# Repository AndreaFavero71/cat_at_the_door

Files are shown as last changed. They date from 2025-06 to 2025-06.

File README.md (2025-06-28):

# CAT AT THE DOOR – A system to detect and notify when your cats are waiting at the door.
<br><br>
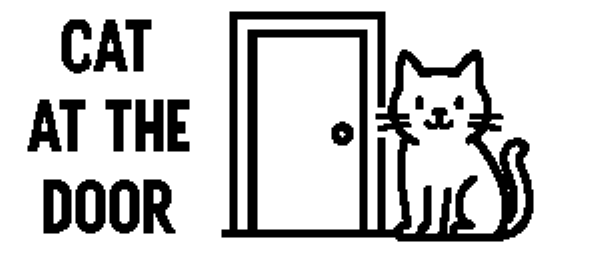
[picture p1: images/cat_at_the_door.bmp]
title image


<br><br>
## Project overview

**CAT AT THE DOOR** is a wireless system that detects when your cat is waiting at the door and notifies you via a portable device.  

It’s ideal if:  
- You cannot install a cat flap or automatic pet door.
- You like to let your cats roam outside.
- You want to be notified the moment your cat is ready to come back in.

This project uses two devices communicating via **LoRa**:
- A **stationary unit** with radar + BLE detection, placed inside near the door.
- A **portable unit** with e-paper display + buzzer, that you carry with you.

<br><br>
## Project motivation
I was perfectly happy building machines no one asked for, until my wife kindly reminded me that we also have cats… not just robots.  
Once I accepted the challenge, the project became increasingly interesting, giving me the opportunity to explore technologies I had never used before.

<br><br>
## Demo video

MACCHIA, one of our cats, comes back home after wandering in the garden for over an hour:

Watch the Demo (https://youtu.be/0kiuHv76AjQ)

<br><br>
## Key features

- Detects when one or more cats approach your door
- Uses BLE tags for individual cat recognition (supports 1–4 cats)
- Radar motion sensing, customizable via Bluetooth app
- Visual notification via e-paper display
- Audible alert via buzzer (optional)
- Portable device is battery-powered with sleep mode
- Communication via LoRa, a **Lo**ng **Ra**nge low-power wireless communication system (reliable even through walls/floors)
- Optional Wi-Fi sync for correct date/time
- Rotary encoder menu interface
- 3D printed cases included (STL & STEP)

<br><br>
## Required hardware (summary)

| Qty | Component | Notes |
|-----|---|---|
| 2 | Heltec Wi-Fi LoRa 32 V3 | With antenna + JST battery connector |
| 1+  | Tile Sticker BLE tag (per cat) | Use the Tile app to activate |
| 1 | HLK TD2010C radar module | Tuned via HLKRadarTool app |
| 1 | 2.9" Waveshare e-paper display | Black & white |
| 1 | 3.7V 2200mAh LiPo battery | For portable device |
| 1 | Rotary encoder + push-button | For settings menu |
| 1 | Buzzer (3.3–5V, with transistor) | For optional alerts |
| | USB-C panel mount sockets | Power and recharging |
| | 3D printed case set | STL and STEP files provided |
| | Aluminum tape | Blocks radar from sensing inside room |
> Please read the manual for full instructions before proceeding.

<br><br>
## Quick start
1. Attach a **Tile Sticker BLE tag** to your cat’s collar and retrieve its MAC address (e.g., using *nRF Connect* app)
2. Flash **MicroPython** onto both Heltec Wi-Fi LoRa 32 V3 boards
3. Upload files via **Thonny** to both boards (portable and stationary)
4. Edit `ble_tags.json` and `config.json` with your own settings
5. Tune radar sensitivity and detection area using the **HLKRadarTool** app
6. Power up both devices and observe how it detects when your cat returns!

> This is not a plug-and-play kit. Expect some assembly, soldering, BLE scanning, and radar tuning.  
> Please read the manual for full instructions before proceeding.

<br><br>
## LoRa Power Negotiation System

This project features a **dynamic LoRa power adjustment** mechanism that minimizes transmission power while maintaining reliability.  
Here's how it works:

1. Both devices begin with the default `tx_power` value set in `config.json`.
2. After each successful data exchange, they evaluate the received signal strength (RSSI):
   - If **RSSI is too low**, the device adds a `<` character to its reply to request **more power**.
   - If **RSSI is too high**, the device adds a `>` to request **less power**.
   - If RSSI is within the configured window, no change is requested.
3. If no reply is received for 4 consecutive transmissions:
   - The sending device increases its transmission power to **22 dBm** temporarily.
4. If no reply is received after 15 failures:
   - It resets the transmission power to the default value, assuming the peer is off.

> This simple yet effective mechanism helps conserve battery life without compromising reliabile communication.

<br><br>
## LoRa Duty-Cycle Compliance

LoRa frequencies and transmission limits are **regulated** in most countries.  
For example, in the EU (including the Netherlands), the max **duty cycle is 1%** (36 sec/hour).

This system:
- Calculates Time-on-Air (ToA) based on your number of cats and LoRa settings
- Automatically increases the transmission interval if the estimated duty cycle exceeds the limit
- Provides console feedback via Thonny when tuning or debugging

> All related parameters (LoRa power, frequency, spreading factor, etc.) are adjustable in `config.json`.

<br><br>
## Detailed manual

All build instructions, tuning tips, and troubleshooting steps are in the downloadable 70+ page guide:  
📄 [How_to_make_CAT_AT_THE_DOOR.pdf](doc/How_to_make_CAT_AT_THE_DOOR.pdf)

| #  | Section | Description |
|----|---|---|
| 1  | Introduction | Project goals and context |
| 2  | Supplies | Full list of parts |
| 3  | Make | 3D printing, wiring, assembling |
| 4  | Program | Flashing and uploading code |
| 5  | Tuning | Radar and BLE tuning |
| 6  | Troubleshooting  | Common issues and fixes |
| 7  | How to use it | Practical operation |
| 8  | Info | Legal, safety, and technical remarks |

<br><br>
## ⚠️ System Limitations

While the system works reliably with proper setup, it’s important to be aware of its current limitations:

- **Radar sensitivity to movements (its own job :smile:)**  
  If the radar moves, it detects movement; The stationary device should not move.  
  The mmWave radar may detect raindrops as movements.

- **Radar tuning is essential**  
  Each installation requires some trial and error. Radar positioning and threshold tuning are necessary and can take time.

- **BLE Tag compatibility**  
  Only BLE tags with fixed MAC addresses can be used. **Apple AirTags** are not compatible due to MAC address randomization.

- **Size of BLE tag**  
  The Tile Sticker is compact but may still feel bulky on very small cats.

- **Not suitable for automatic door control**  
  This project only **notifies** when your cat is outside, it does **not open** any doors or actuators.

- **Radar field of view**  
  The mmWave radar has an approximate horizontal detection angle of **60 degrees**. This is sufficient to cover a door-sized area.  
  However, if your cat tends to return from wider angles or corners not covered by this range, you may need to reposition the radar.  
  Adding a second radar module shouldn't take too much effort, and it would surely wider the coverage.

- **Intermediate DIY skills**  
  Basic soldering, 3D printing, and firmware flashing are required. Beginners can follow the guide, but the effort is non-trivial.

> Despite these limitations, with a bit of care during setup, the system proves to be a helpful, fun, and very practical solution.

<br><br>
## Where to begin

If you're interested:

1. Skim the manual once to get a general idea.
2. Let it sit for a day—yes, really!
3. Read it again more carefully.
4. You'll then know exactly what to do next.

<br><br>
_Made by Andrea Favero – for our cats Freya and Macchia_

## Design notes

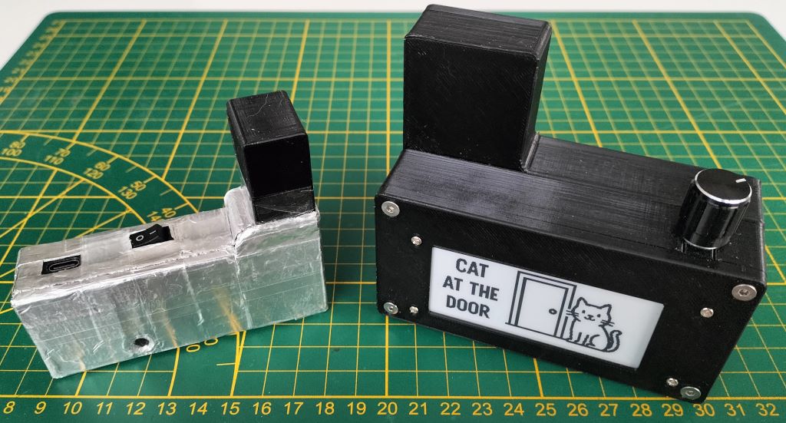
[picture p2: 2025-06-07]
images/devices.jpg

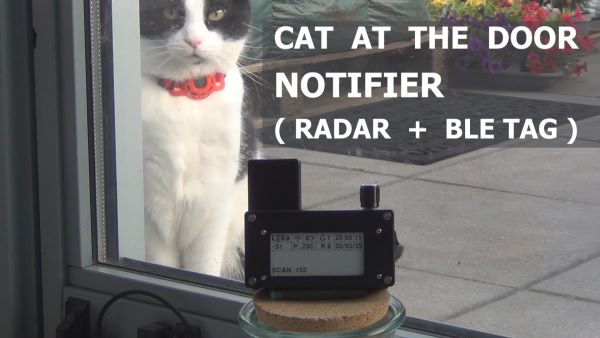
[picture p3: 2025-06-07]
images/title.jpg

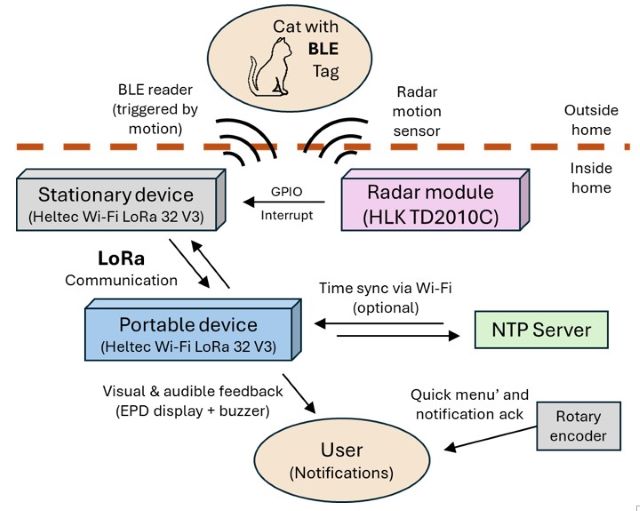
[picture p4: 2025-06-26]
images/System_achitecture.jpg

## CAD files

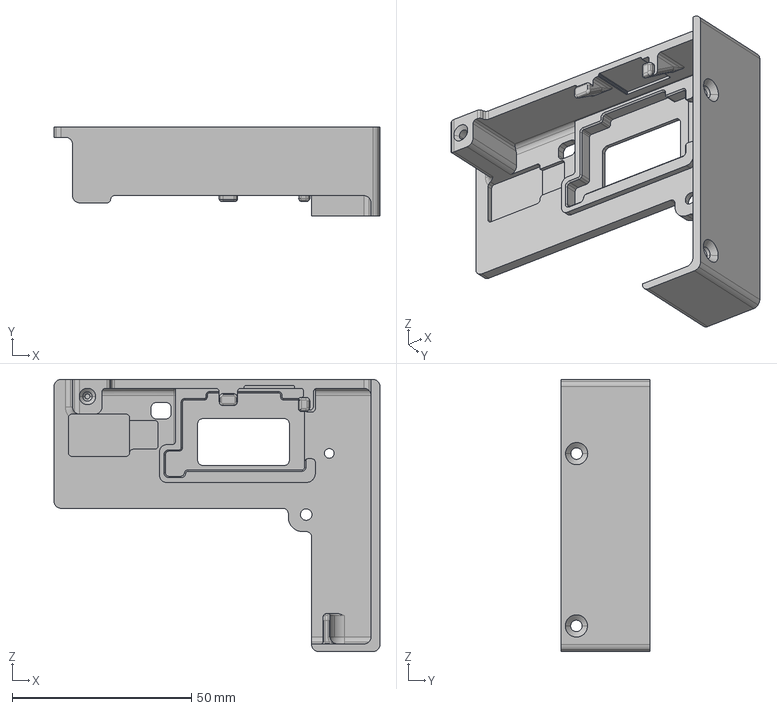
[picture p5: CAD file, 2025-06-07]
stp/Cover_stationary.stp
91.0 x 24.9 x 76.0 mm

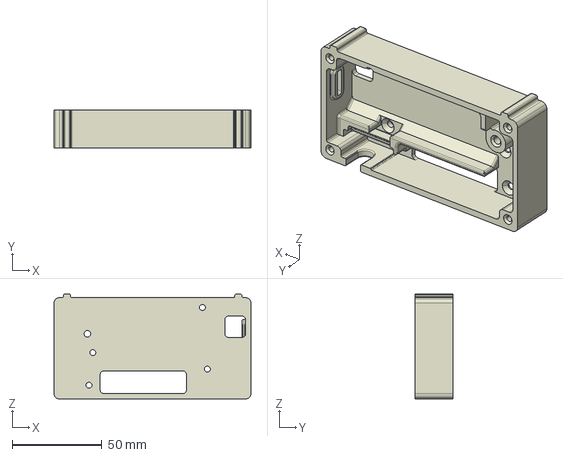
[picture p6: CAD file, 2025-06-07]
stp/Case_EPD_portable.stp
109.6 x 20.9 x 58.4 mm

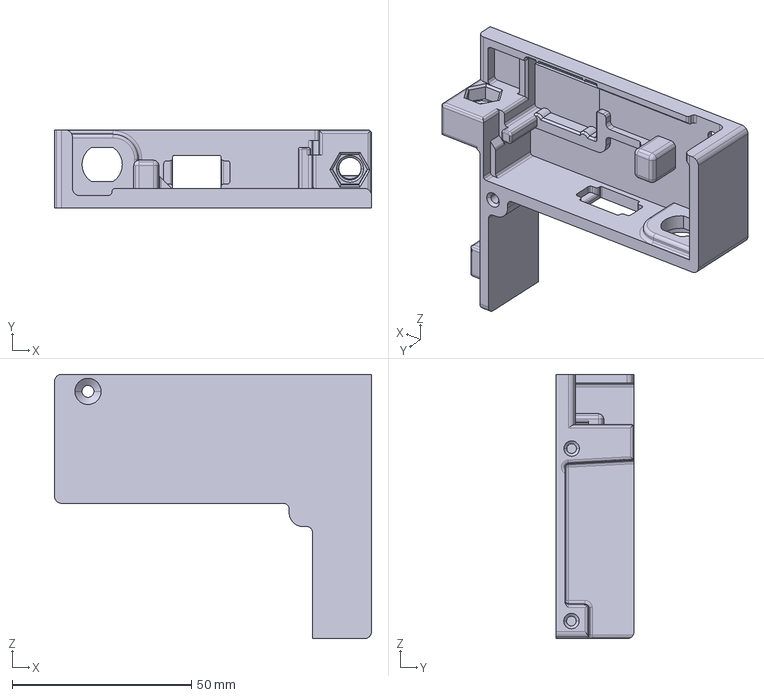
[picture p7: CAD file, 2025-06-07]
stp/Case_stationary.stp
88.4 x 21.8 x 73.8 mm

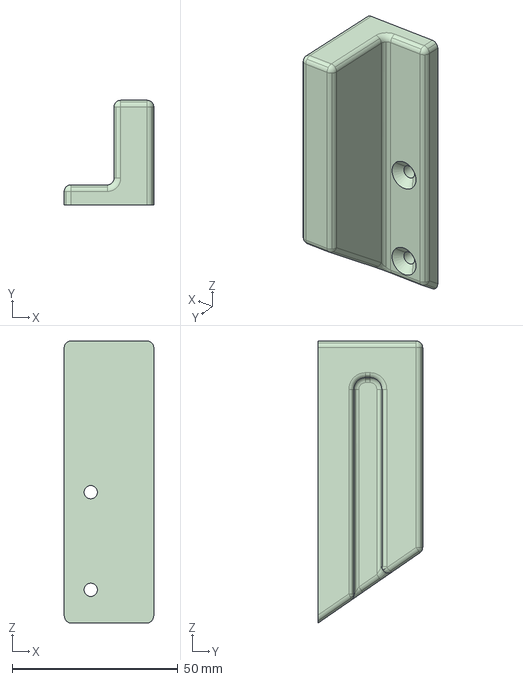
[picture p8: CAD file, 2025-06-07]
stp/Support_L.stp
27.0 x 31.5 x 85.0 mm

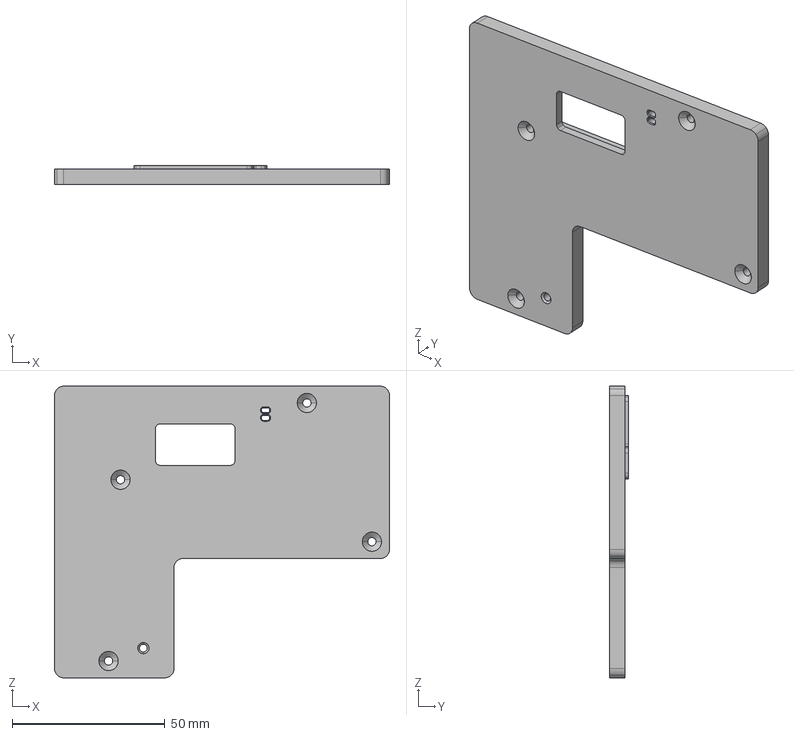
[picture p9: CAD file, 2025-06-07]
stp/Cover_Board_portable.stp
109.6 x 6.22 x 95.4 mm

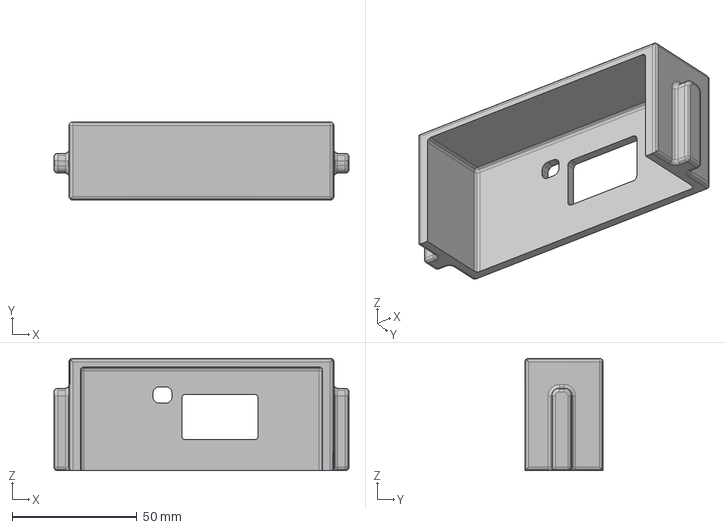
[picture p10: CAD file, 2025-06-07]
stp/Over_cover.stp
118.0 x 31.3 x 45.0 mm

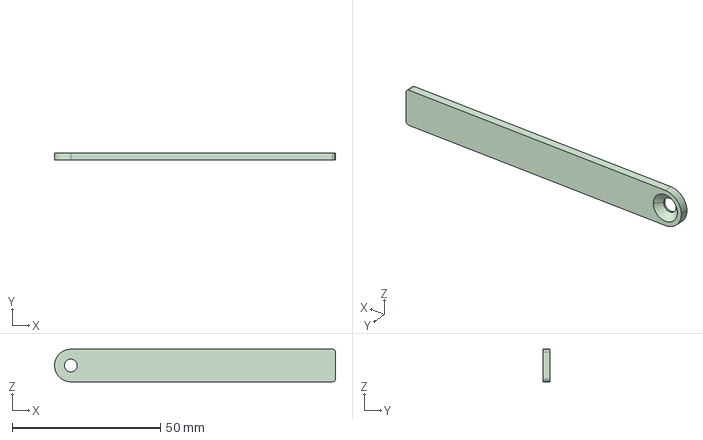
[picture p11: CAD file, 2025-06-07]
stp/Battery_holder.stp
94.7 x 2.50 x 11.0 mm

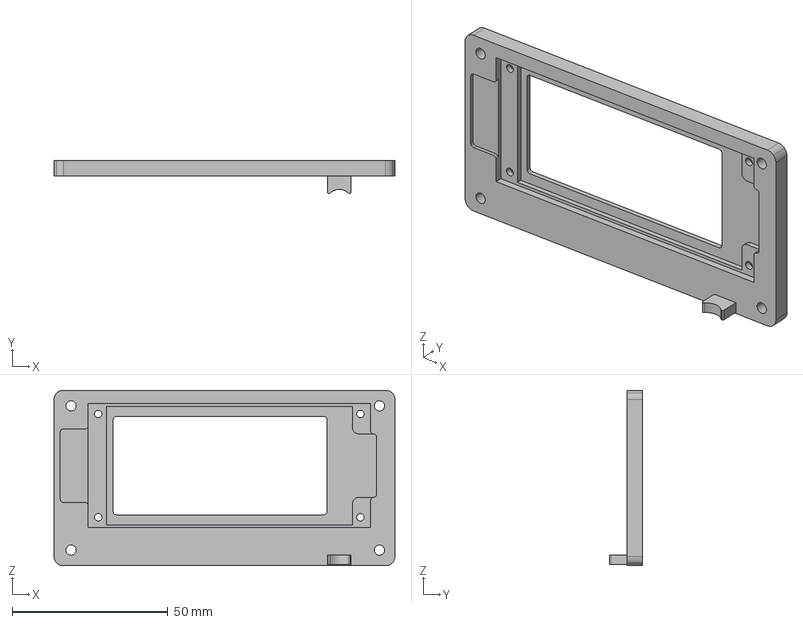
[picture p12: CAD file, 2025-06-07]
stp/Cover_EPD_portable.stp
109.6 x 10.8 x 56.4 mm

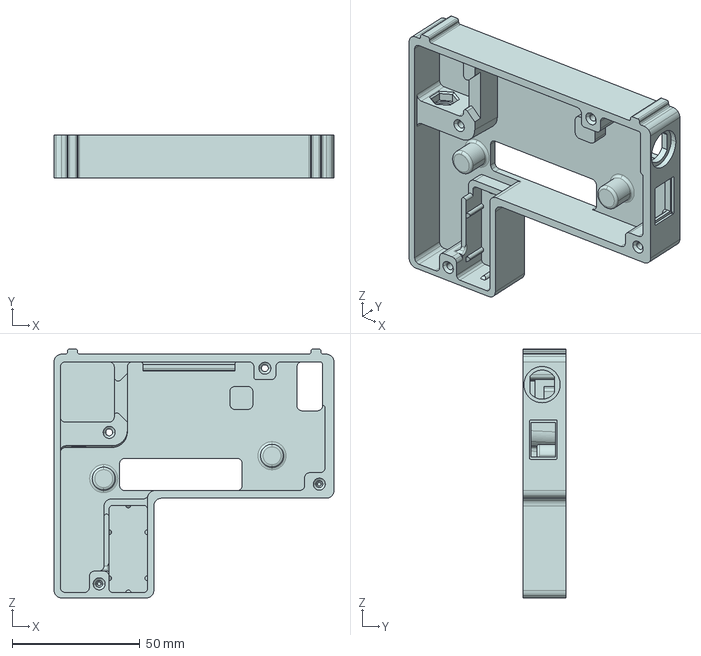
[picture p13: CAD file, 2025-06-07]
stp/Case_Board_portable.stp
109.6 x 17.0 x 97.4 mm

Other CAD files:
stp/Support_R.stp
stl/Battery_holder.stl
stl/Case_Board_portable.stl
stl/Case_EPD_portable.stl
stl/Case_stationary.stl
stl/Cover_Board_portable.stl
stl/Cover_EPD_portable.stl
stl/Cover_stationary.stl
stl/Over_cover.stl
stl/Support_L.stl
stl/Support_R.stl

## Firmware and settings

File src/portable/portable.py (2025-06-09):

"""
Andrea Favero, 20250608

'Door at the door' project
Code for the portable device
Rev 0.2


Hardware:
- Heltec WiFi LoRa 32 V3 board (based on ESP32-S3)
- e-ink 2in9V2 display (B&W) from Waveshare
- LiPo battery
- Encoder
- buzzer


High level Logic:
- Portable device periodically inquires the stationary device, via LoRa.
- The stationary device replies with info whether 'cats at the door' are detected.
- If cats are detected, the buzzer is activated and info are plot to the screen.
- Via the encoder push-button the buzzer can be stopped.
- 'cats at the door' reminder comes back to screen.
- 'cats at the door' reminder can be ackowledged by a long push-button pressing.


Energy:
- Portable device uses about 80 mWh, when LoRa updates every 20s.
- In between LoRa connections:
   - LoRa chip (SX1262) goes in sleep mode (settings retention).
   - MCU goes in lightsleep, if radar doesn't detect something.
- MCU goes deepsleep if timeout is reached (device forgotten 'ON').
- Inform the other device to adjust the LoRa signal power when too low or too high.


EPD Display:
- LoRa icon, if latest coomunication was established, and signal strenght.
- WiFi icon, if latest WiFI connection was established.
- Battery icon, with charge level periodically checked on the battery voltage.
- Bel icon if enabled, and related number of buzzer repeats
- Date and time.
- Cat icon when the stationary's device radar has sensed something.
- Cat's name and BLE tag RSSI level, when radar senses and BLE in range.
- Timeout icon right before deepsleep, if timeout is reached.


Config:
- Most of the settings in config.json file.
- Cats'names and related ble mac addresses in ble_tags.json
"""




###########################################################################################
# prints to the Shell to show the code is running #########################################
###########################################################################################

print(f"\n{'#' * 60}")
print(f"{'#' * 12}    Portable device started ...    {'#' * 13}")
print(f"{'#' * 60}\n")



###########################################################################################
# EPD library import and fast feedback on display #########################################
###########################################################################################

from epd2in9_V2 import EPD, Display                 # import edp driver

with open("lib/welcome_icon.bin", "rb") as f:       # opens the binary file with welcome bmp image
    welcome_icon = bytearray(f.read())              # makes a bytearray from the image

epd = EPD(width=128, height=296, orientation=90)    # valid orientations are 0, 90 and 180
epd.init_Fast()           # wake the epd up from sleep
epd.buffer = welcome_icon # fills the framebuffer with the welcome_icon
epd.get_buffer()          # rotates buffer and send it to EPD (portrait write to EPD, taking ca 60ms)
epd.display()             # plots the buffer to the display (takes ca 1.8 secs)
epd.sleep()               # prevents display damages on the long run (command takes ca 100ms)

welcome_icon = None       # release welcome_icon to free up some memory 



###########################################################################################
# Libraries import ########################################################################
###########################################################################################

from machine import Pin, ADC, PWM, RTC, Timer, deepsleep, lightsleep, WDT, SoftI2C
from machine import reset_cause, PWRON_RESET, HARD_RESET, WDT_RESET, DEEPSLEEP_RESET, SOFT_RESET

import sys, network, ntptime, json, ubluetooth, gc, ssd1306, utime, struct

from datetime_converter import DateTimeConverter    # date time conversion w/wo internet
from rotary_irq_esp import RotaryIRQ   # import for the encoder knob
from esp32 import mcu_temperature      # import for mcu temperature check
from sx1262 import SX1262              # import for LoRa communication

# import for edp display
from icons import Icons                # import custom icons
from writer import Writer              # library for text
import helvetica22bold                 # import for edp display
import helvetica26bold                 # import for edp display



###########################################################################################
# System controls #########################################################################
###########################################################################################

# setting for the Watch Dog Timer
WDT_ENABLED = True



###########################################################################################
# Constants ###############################################################################
###########################################################################################


# hardware setup for rotary Encoder
PUSH_BUTTON = Pin(4, Pin.IN, Pin.PULL_UP)  # pin for the push button of the encode


# hardware setup for buzzer
BUZZER = PWM(Pin(5), freq=1000, duty_u16=65535)  # Start OFF (transistor inverts logic)
buzzer_timer = Timer(2)                  # Virtual timer if -1


# Set a NTP server, for date time synchronization (should preferibly consider area of living)
ntptime.host = "europe.pool.ntp.org"
ntptime.timeout = 10                     # timeout in seconds


# settings for different time related controls
NTP_UPDATE_INTERVAL_S = 1800             # period (in secs) in between the RTC alignmento to NTP
BATTERY_CHECK_INTERVAL_S = 300           # period (in secs) in between battery level check


# settings file
FILE_NAME_CONFIG = "config.json"         # file storing most of the settings


# settings for BLE tags scanner
FILE_NAME_TAGS = "ble_tags.json"         # file to store the BLE tags mappings
BLE_SCAN_TIME = 10                       # seconds to scan for BLE devices
BLE_RSSI_THRESHOLD = -80                 # ignore devices with RSSI below this value


# settings for battery voltage check
ADC_CTRL = Pin(37, Pin.OUT)              # GPIO37 enables battery voltage measurement
ADC_IN = Pin(1)                          # GPIO1 reads battery voltage
adc_bat = ADC(ADC_IN)                    # adc object
adc_bat.atten(ADC.ATTN_11DB)             # 11dB attenuation (input range up to ~3.3V)
V_REF = 3.3                              # ADC reference voltage (assuming ESP32 powered at 3.3V)
DIVIDER_RATIO = 4.9                      # voltage divider ratio: (R14 + R13) / R14 = (100 + 390) / 100
VBAT_READINGS = 20                       # number of readings for averaging
CORRECTION = 1.048                       # correction of adc reading vs measured (multimeter)


# settings for dynamic adustment of the LoRa transmission power
MIN_LORA_RSSI_TARGET = -100              # min LoRa rssi signal level, to provide feedback to sender
MAX_LORA_RSSI_TARGET = -80               # max LoRa rssi signal level, to provide feedback to sender
LORA_TX_POWER_MIN = -9                   # min possible for SX1262
LORA_TX_POWER_MAX = 22                   # max possible for SX1262
MIN_MISSED_PACKETS = 4  # lower number of LoRa missed connections to bring the LoRa power to MAX
MAX_MISSED_PACKETS = 15 # upper number of LoRa missed connections to give up (bring the LoRa power to NOM)   

###########################################################################################
# settings ################################################################################
###########################################################################################

# setting for the oled display usage
oled_disp_enabled = False           # this variable gets updated from the config.json setting


# setting for the wifi usage
wifi_enabled = False                # this variable gets updated from the config.json setting


# push button settings
debounce_timer = Timer(0)           # timer-based debounce
push_button_block_timer = Timer(1)  # a second timer for the bush button debouncing
push_button_blocked = False         # flag to prevent repeated triggers
button_pressed = False              # flag to track if the encoder push button is pressed


# variables related to LoRa communication
lora_connect_status = False         # flag tracking the LoRa connection status
lora_connect_counter = 0            # counter tracking the number of succesfull LoRa connections
prev_lora_connect_counter = 0       # counter holding the number of succesfull LoRa connections at previous cycle
lora_last_connect_time_ms = 0       # (global) holds latest LoRa connection time (ms) to stationary device
lora_rssi = None                    # lora_rssi is initially set to None
missed_lora_packets = 0             # counter of consecutive missed LoRa packages
lora_tx_power = 0                   # LoRa power, later get update by the config.json
initial_lora_tx_power = 0           # initial LoRa power, later get update by the config.json
lora_rssi_sender = None             # lora_lora_rssi_sender is initially set to None
lora_sender_pwr_action = ""         # (one char) string for LoRa tx power adjustment at sender
query = ""                          # query string send buy the portable device 
toa_us = 0                          # Time-on-Air is microseconds

# variables related to the radar detection status (info via LoRa communication)
radar_detection = False             # gets updated based on responder device info


# cat detection related initial variables
cat_at_door_flag = False            # flag to track the presence of cats at the door
cat_at_door_reminder = False        # flag to track the presence of cats at the door has happened
cats_at_the_door = []               # list of cat's names detected via BLE, reset via button_pressed
cats_lbe_rssi = []                  # list of lbe rssi detected via BLE
cat_at_door_time = 0                # time used to idle after user aknowledges cat_at_the_door notification
buzzer_done = 0                     # counter of the times the buzzer has been activated


# battery voltage initial variabile
battery_voltage_list = []           # initialize list holdist the last voltage measurements
battery_voltage = 0                 # initialize variable holding the battery voltage
battery_level = 0                   # initialize variable holding the battery level
last_battery_check_time = 0         # initialize variable holding the last battery check time


# system related initial variables
wifi_connected = False              # flag to track the wifi connection status
oled_display_menu = False           # flag to track when dealing with the menu on screen


# mcu temperature of portable device is used as initial mcu temp of the stationary device
last_stat_mcu_temp = mcu_temperature()


###########################################################################################
# functions ###############################################################################
###########################################################################################

def load_config(fname):
    """Load configuration from JSON file"""
    
    try:
        with open(fname, 'r') as f:
            config = json.load(f)
        return config
    except e:
        print(f"Error while loading {fname} : {e}")
        sys.exit(1)
        


def load_tag_ids(fname):
    """Function loading tags related info, from JSON file"""
    
    try:
        with open(fname, "r") as f:
            return json.load(f)
    except e:
        print(f"Error while loading {fname} : {e}")
        sys.exit(1)



def decode_my_ble_tags(my_ble_tags):
    """
    Decodes the tags dictionary into 3 lists.
    Each cat gets an idx number, for faster LoRa communication.
    One string for 'no cats at the door' is also returned   
    """
    
    cats_idx     = []
    cats_names   = []
    cats_macs    = []
    no_cats_text = ""
    cats_number = len(my_ble_tags)
    
    for idx in range(cats_number):
        if my_ble_tags[str(idx)]["name"] != "" :
            cats_idx.append(idx)
            cats_names.append(my_ble_tags[str(idx)]["name"])
            cats_macs.append(my_ble_tags[str(idx)]["mac"])
            no_cats_text+= str(idx) + "0,"
    no_cats_text = no_cats_text[:-1]    # removal of the last comma
    
    return cats_number, cats_idx, cats_names, cats_macs, no_cats_text



def init_oled_backlight(config):
    """Initialize the backlight control pin for oled display"""
    
    oled_backlight_pin = Pin(config['oled_display']['oled_backlight_pin'], Pin.OUT, value=1)  # Start with backlight off
    return oled_backlight_pin



def get_reset_reason():
    """Checks the reason for the MCU boot, in essence what happened at the power off (WDT, DeepSleep, etc)."""
    
    reset_reason = reset_cause()          # Get reset cause
    reset_message = {
        PWRON_RESET:     "POWER-ON RESET",
        HARD_RESET:      "HARD RESET",
        WDT_RESET:       "WATCHDOG RESET",
        DEEPSLEEP_RESET: "DEEPSLEEP WAKE",
        SOFT_RESET:      "SOFT RESET"
        # machine.BROWNOUT_RESET is missing in some MicroPython versions
    }.get(reset_reason, f"???: {reset_reason}")
    
    return reset_reason, reset_message



def load_counter():
    """
    Load a counter from the RTC memory.
    This is used to properly count the timeout also in case of unwanted reboots, like WDT.
    """
    
    data = rtc.memory()          # reads the RTC memory
    if len(data) != 2:           # check is two bytes
        return None              # Memory invalid
    try:                         # tenattive approach
        val = struct.unpack(">H", data)[0]  # rom bytes to integer
        return val               # counter is returned
    except Exception:            # case of exceptions
        return None              # corrupt format



def save_rtc_counter(val):
    """Save the counter to the RTC memory"""
    
    rtc.memory(struct.pack(">H", val))



def get_wlan(config):
    """
    Connects to the WLAN.
    It attempts for 20 secs.
    It return the wlan object and a flag about connection result (succcess or failure).
    """
    
    print("Activating WLAN function ...")
    wlan_connected = False
    print_once = True
    max_time_ms = 20000
    t_ref = utime.ticks_ms()

    wlan = network.WLAN(network.STA_IF)
    wlan.active(True)
    
    while utime.ticks_ms() - t_ref < max_time_ms:
        if not wlan.isconnected():
            try:
                wlan.connect(config['wifi']['ssid'], config['wifi']['password'])
            except OSError as e:
                print(e)
                break

            while not wlan.isconnected():
                if utime.ticks_ms() - t_ref > max_time_ms:
                    print(f"Timeout of {int(max_time_ms/1000)} secs on getting WiFi connection")
                    break
        
        elif wlan.isconnected():
            wlan_connected = True
            print("Wlan is active")
            print(f"Network config: {wlan.ifconfig()}\n")
            return wlan, wlan_connected
    
    if not wlan_connected:
        print("Network connection filed")
        return None, False



def is_wifi_connected():
    "Check if WLAN is connected"
    
    wlan = network.WLAN(network.STA_IF)
    return wlan.isconnected()



def sync_time(utc_shift, dst_shift):
    "Synchronize date and time via WLAN and NTP"
    
    print("Updating RTC from NTP ...")
    try:
        ntptime.settime()                   # Get UTC time
        local_time = utime.localtime()      # Convert to structured time
        yearday = local_time[7]             # Get day of the year

        # Determine the correct time shift
        if 85 <= yearday < 300:             # Roughly summer (DST)
            hour_offset = utc_shift + dst_shift  # hour shifter considers utc and dst
        else:                               # Roughly winter (standard time)
            hour_offset = utc_shift         # hour shifter considers utc

        # Apply time correction
        local_time = list(utime.localtime(utime.mktime(utime.localtime()) + hour_offset * 3600))
        print("RTC updated via NTP")
        return True, local_time[:6]         # Return (year, month, day, hours, minutes, seconds)

    except Exception as e:
        print(f"Error on updating RTC from NTP: {e}")
        return False, ()



def get_date_time(converter, ntp_reached, date_time, utc_shift, dst_shift):
    """
    In between NPT connections, it converts from epoch to date and time individual fields.
    Right after an NTP connection, it separates the date and time fields from a list.
    """
    
    if ntp_reached:                        # Case the NTP was reachable
        year, month, day, hours, minutes, seconds = date_time
        print(f"{day:02d}/{month:02d}/{str(year)[2:]}  {hours:02d}:{minutes:02d}\n")
    else:                                  # Case the NTP was not reachable
        now = utime.time()                 # Epoch time from RTC of the board
        # time is split via the converter.unix_to_datetime (no libraries, ca 2ms)
        year, month, day, hours, minutes, seconds = converter.unix_to_datetime(now, utc_shift, dst_shift)
    return year, month, day, hours, minutes, seconds



def update_time(now, last_ntp_time_update, NTP_UPDATE_INTERVAL_S, first_time = False):
    "Updates the time, and handles exceptions"
    
    ntp_reached = False
    
    if wifi_enabled and is_wifi_connected() and (first_time or now > last_ntp_time_update + NTP_UPDATE_INTERVAL_S):
        ntp_reached, date_time = sync_time(utc_shift, dst_shift)  # Get the time from NTP (corrected by uts nad dst shifts)
    
    if ntp_reached:
        year, month, day, hours, minutes, seconds = get_date_time(converter, True, date_time, utc_shift, dst_shift)
        now = utime.time()            # Epoch time is assigned to now
        last_ntp_time_update = now    # now is assigned to last_ntp_time_update  
    else:
        year, month, day, hours, minutes, seconds = get_date_time(converter, False, '', utc_shift, dst_shift)
    
    date_time = f"{day:02d}/{month:02d}/{str(year)[2:]}  {hours:02d}:{minutes:02d}:{seconds:02d}"
    return last_ntp_time_update, date_time



def init_lora(config):
    "Setup the Lora communication."

    print("Activating LoRa ...")
    
    lora_tx_power = int(config['lora']['tx_power'])  # TX power in dBm
    initial_lora_tx_power = lora_tx_power
    print(f"Initial LoRa transmission power: {lora_tx_power} dB")
    
    try:
        lora_sx = SX1262(spi_bus = int(config['lora']['spi_bus']),
                     clk =     Pin(int(config['lora']['clk_pin'])),
                     mosi =    Pin(int(config['lora']['mosi_pin'])),
                     miso =    Pin(int(config['lora']['miso_pin'])),
                     cs =      Pin(int(config['lora']['cs_pin'])),
                     irq =     Pin(int(config['lora']['irq_pin'])),
                     rst =     Pin(int(config['lora']['rst_pin'])),
                     gpio =    Pin(int(config['lora']['dio1_pin']))
                     )

        # configure LoRa parameters
        lora_sx.begin(freq =   int(config['lora']['frequency_MHz']),  # Frequency in MHz
                      bw =     float(config['lora']['bw_KHz']),       # Bandwidth in kHz
                      sf =     int(config['lora']['spread_factor']),  # Spreading factor
                      power =  lora_tx_power,                         # TX power in dBm
                      cr=7,                  # Coding rate (8 is stronger forward error correction)
                      syncWord=0x12,         # Sync word
                      currentLimit=60.0,     # Current limit in mA
                      preambleLength=6,      # Preamble length  (6 is min, 8 is rather common)
                      implicit=False,        # Implicit header mode
                      implicitLen=0xFF,      # Implicit header length
                      crcOn=True,            # CRC enabled
                      txIq=False,            # TX IQ inversion
                      rxIq=False,            # RX IQ inversion
                      tcxoVoltage=1.7,       # TCXO voltage
                      useRegulatorLDO=False, # Use LDO regulator
                      blocking=True          # Blocking mode
                      )

        lora_sx.setBlockingCallback(False, lora_callback)
        print("LoRa is active\n")
        return lora_sx, lora_tx_power, initial_lora_tx_power
    
    except Exception as e:
        print(f"Error while activating LoRa{e}")
        sys.exit(1)
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

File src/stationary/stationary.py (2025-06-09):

"""
Andrea Favero 20250608



'Door at the door' project
Code for the stationary device (essentially a LoRa sensor)
Rev 0.1

################################################################################
##### had to remove the display functions, as I mechanically broke it during ###
##### the last assembly. Cut the flat cable to prevent more issues.          ###
################################################################################

Hardware:
- Heltec WiFi LoRa 32 V3 board (based on ESP32-S3)
- Radar HLK LD2010C (set via the app HLKRadarTool)

Logic:
- Stationary device keeps monitoring the radar signal (output pin)
- When it receives a "check" via the LoRa:
    - if the radar does not sense, it replies with 'no_cats_text' via LoRa.
    - if the radar senses the BLE scans for BLE tags, ad replies via LoRa with 'r' + cats-status.
    - if initial idling, it replies with 'd' + cats-status ('d'eactivated radar).
    - N times (4) out of M (80) it prepend the MCU temperature 'txx' in deg. Celsius.

Setting to apply to the radar, via the HLKRadarTool app:
  HLK LD2010C: set output pin active LOW
  HLK LD2010C: set "Unmanned duration" to 20s; This forces the output pin signal to stay active for at least this period

"""

###########################################################################################
# Libraries import ########################################################################
###########################################################################################

from machine import Pin, SoftI2C, PWM, lightsleep, WDT
from esp32 import mcu_temperature      # import for mcu temperature check
from sx1262 import SX1262              # import for LoRa communication
import sys, utime, json, bluetooth



###########################################################################################
# System controls #########################################################################
###########################################################################################

# setting for the Watch Dog Timer
WDT_ENABLED = True



###########################################################################################
# Constants ###############################################################################
###########################################################################################

WHITE_LED_PIN = Pin(35, Pin.OUT, value=0 )   # output pin for the onboard white led, initially set low (led off)
RADAR_PIN =     Pin(6, Pin.IN, Pin.PULL_UP)  # input pin as Pull UP prevents active signal when the HLK LD2010C radar is un-powered

FILE_NAME_CONFIG = "config.json"         # file storing overall settings
FILE_NAME_TAGS = "ble_tags.json"         # file storing BLE tags mappings

OLED_REFRESH_PERIOD_MS = 2000            # cadence for the info refreshment at oled display

MCU_TEMP_RUN_CADENCE = 80                # cadence of sending mcu temperature via LoRa ( 4 out of this Value)

# settings for dynamic adustment of the LoRa transmission power
MIN_LORA_RSSI_TARGET = -100              # min LoRa rssi signal level at receiver, to feedback the sender
MAX_LORA_RSSI_TARGET = -80               # max LoRa rssi signal level at receiver, to feedback the sender
LORA_TX_POWER_MIN = -9                   # min possible LoRa power for SX1262
LORA_TX_POWER_MAX = 22                   # max possible LoRa power for SX1262
MIN_MISSED_PACKETS = 4    # min number of missed LoRa connections, to bring the LoRa power to MAX
MAX_MISSED_PACKETS = 15   # max number of missed LoRa connections to give up (bring the LoRa power to NOM)



###########################################################################################
# settings ################################################################################
###########################################################################################

# set WDT related variables
if WDT_ENABLED:                          # case the WDT_ENABLED is set True
    wdt = WDT(timeout=60000)             # 60s watchdog
    radar_detection = 0                  # flag to track the radar output status

oled_disp_enabled = False                # this variable gets updated from the config.json setting

oled_brightness = {0:65475, 1:65465, 2:65455, 3:60450, 4:55450} # 0=min, 4 = max

prev_radar = 0                           # initial radar variables

mcu_temp = 0                             # mcu temperature is initially set to zero

lora_rssi = None                         # lora_rssi initially set to None, later a negative integer
missed_lora_packets = 0                  # counter of consecutive missed LoRa packages
initial_lora_tx_power = 0                # initial LoRa power, later get update by the config.json
lora_rssi_sender = None                  # lora_rssi_sender initially set to None, later from 0 to 2
lora_sender_action = ""                  # (one char) string for LoRa tx power adjustment at sender
toa_us = 0                               # Time-on-Air is microseconds

###########################################################################################
# functions ###############################################################################
###########################################################################################


def load_config(fname):
    """Load configuration from JSON file"""
    print("\nLoading the configuration ...")
    try:
        with open(fname, 'r') as f:
            config = json.load(f)
        print("Configuration loaded\n")
        return config
    except Exception as e:
        print(f"Error while loading {fname} : {e}")
        sys.exit(1)



def load_tags_ids(fname):
    """Function to load tags IDs"""
    print("\nLoading the BLE tags mapping ...")
    try:
        with open(fname, "r") as f:
            print("BLE tags mapping loaded\n")
            return json.load(f)
    except Exception as e:
        print(f"Error while loading {fname}: {e}")
        sys.exit(1)
    


def decode_my_ble_tags(my_ble_tags):
    """Decode my_ble_tags dictionary"""
    cats_idx, cats_names, cats_macs, no_cats_text = [], [], [], ""
    
    for idx in range(len(my_ble_tags)):
        cats_idx.append(idx)
        cats_names.append(my_ble_tags[str(idx)]["name"])
        cats_macs.append(my_ble_tags[str(idx)]["mac"])
        no_cats_text+= str(idx) + "0,"
    no_cats_text = no_cats_text[:-1]    # removal of the last comma
    
    return cats_idx, cats_names, cats_macs, no_cats_text
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

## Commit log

2025-06-09 Improved LoRa settings
    Added CR and ToA duty-cycle to config.json
    Portable device cross-check the settings if within duty-cycle
    Improved LoRa Tx power management
    Improved Instructions
    Other minor improvements in the code
2025-06-26 Improved readme.md
    Added System_architecture.jpg
    Added some info about the LoRa power negotiation and duty-cycle check by the code.
2026-09-26 From Tile Sticker to Holyiot NRF52810 beacon
    This commit updates the project docs and hardware notes from Tile Sticker support to the Holyiot NRF52810 beacon, refreshes the portable device firmware for LoRa and EPD stability, and adds the new config structure for BLE tags and refresh cadence. It also fixes several portable-device bugs in battery monitoring, button handling, status parsing, and display refresh behavior while updating the default sample settings for the current setup.
2026-10-18 Refine portable firmware and NTP logic
    This update modifies the handheld device's firmware, preventing the simultaneous handling of Wi-Fi/NTP, RTC status monitoring, battery management, and memory management for EPD rendering. Additionally, it removes the parameter concerning the EPD full-refresh frequency from the `config.json` file and updates the release notes and documentation for the current firmware version.
